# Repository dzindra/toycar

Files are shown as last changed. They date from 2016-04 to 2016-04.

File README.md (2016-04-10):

# WiFi controlled toy car

Made as a present for my friend's birthday 

* ESP-8266 with NodeMCU
* L293 dual H-bridge driver
* Small geared DC motors
* Pololu wheels and idler
* 3D printed case
* iOS app for car control

## Photos

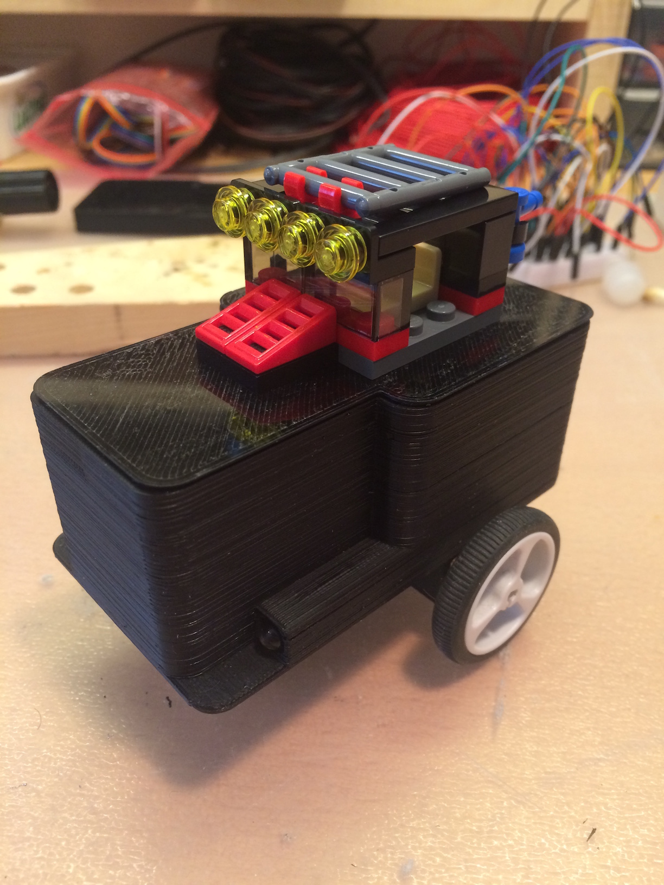
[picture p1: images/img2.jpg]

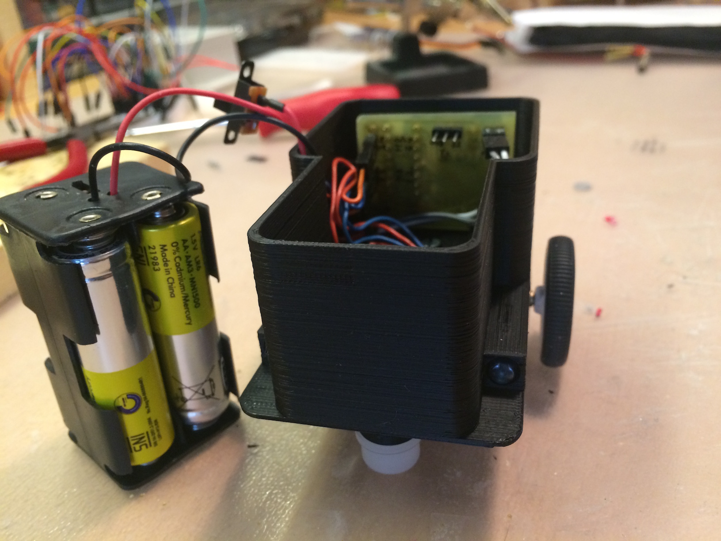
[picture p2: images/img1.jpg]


## Schematic and PCB

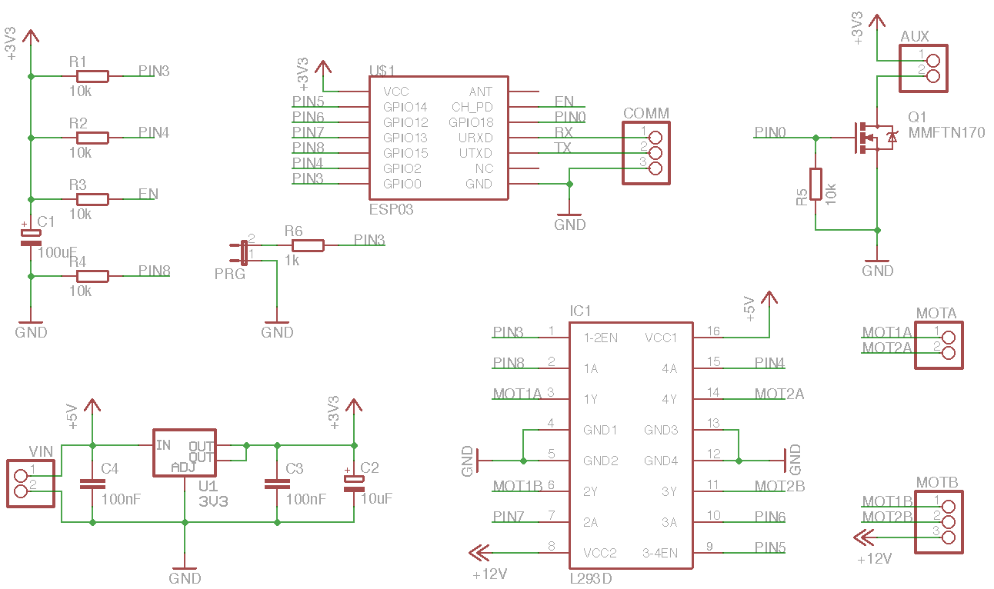
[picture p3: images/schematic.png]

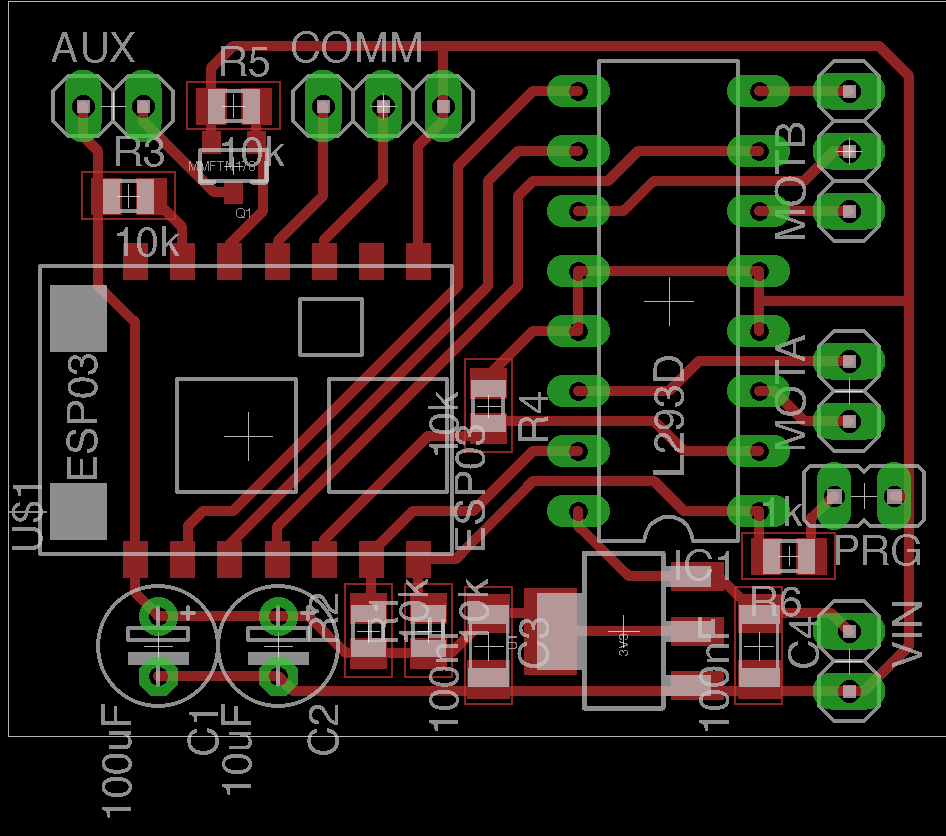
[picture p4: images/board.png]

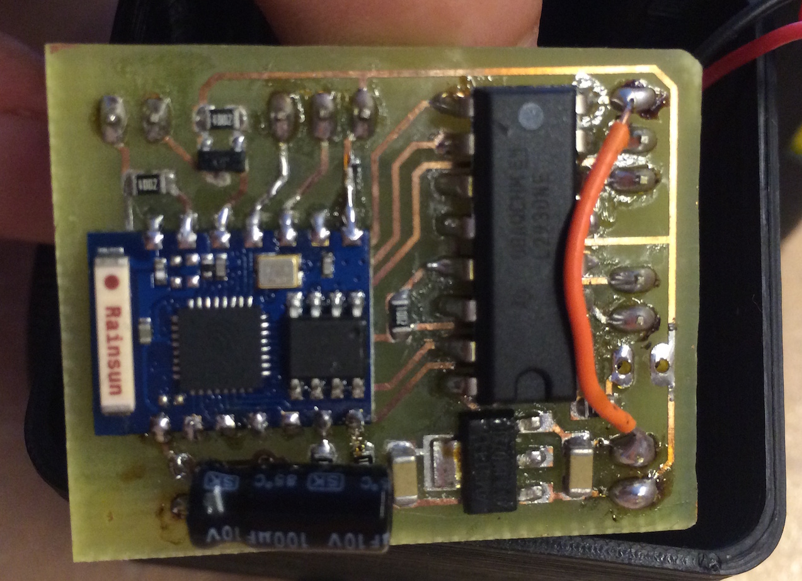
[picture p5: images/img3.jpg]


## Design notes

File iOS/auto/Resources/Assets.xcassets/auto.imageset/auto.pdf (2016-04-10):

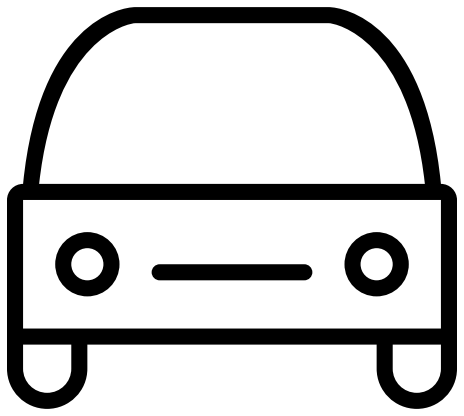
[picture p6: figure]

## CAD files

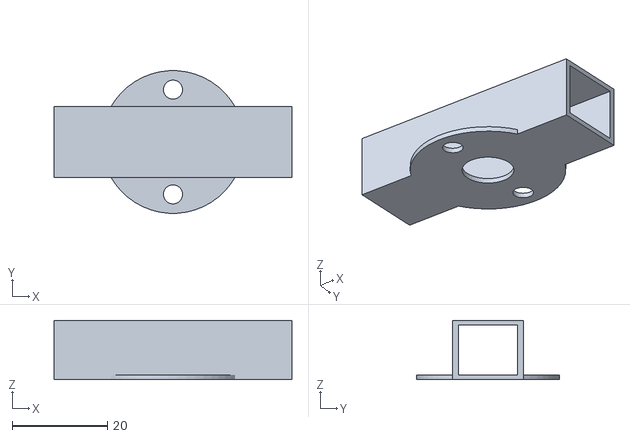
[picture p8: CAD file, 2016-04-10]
stl/motor-holder.stl
50.0 x 29.9 x 12.5

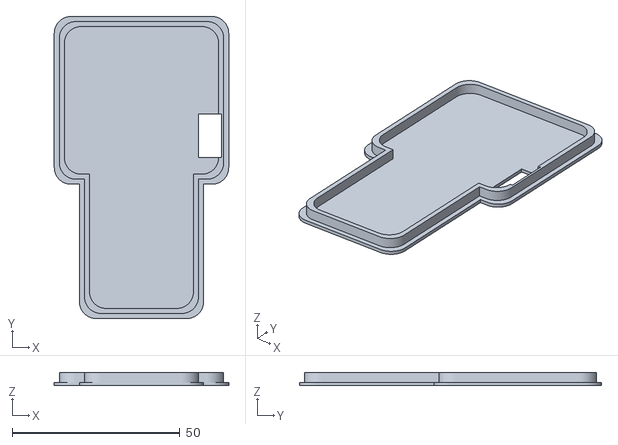
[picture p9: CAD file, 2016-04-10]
stl/top-lid.stl
52.0 x 90.0 x 4.00

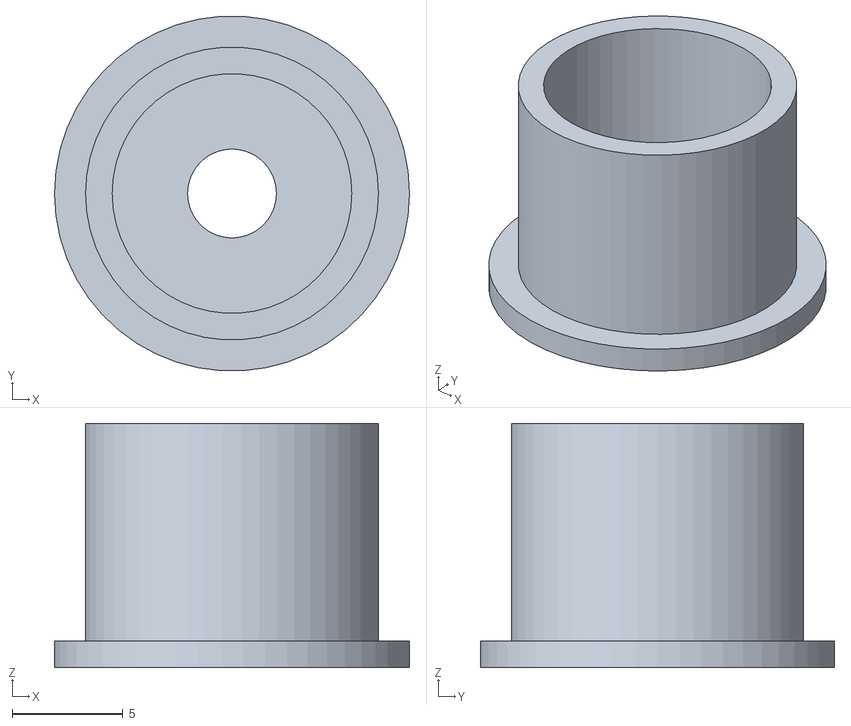
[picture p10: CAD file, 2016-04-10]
stl/idler.stl
16.0 x 16.0 x 11.0

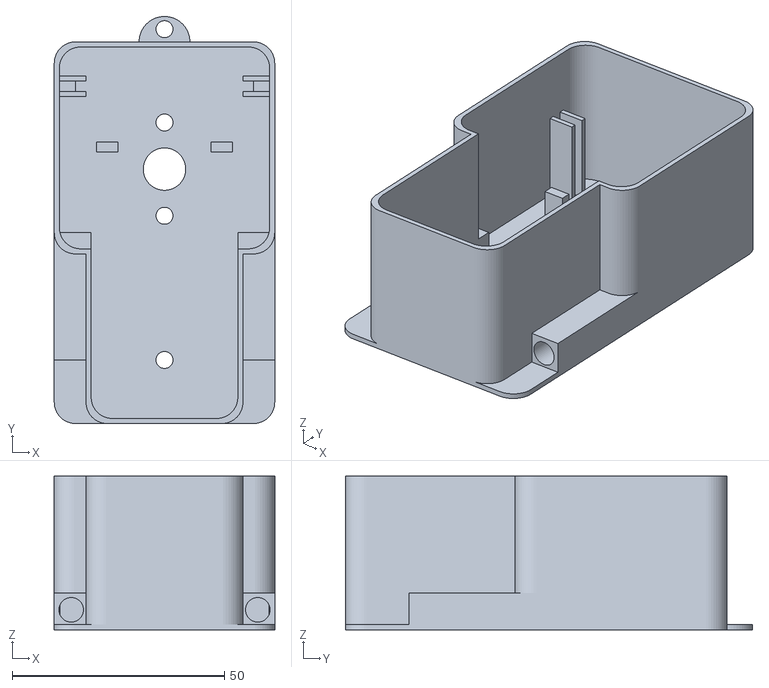
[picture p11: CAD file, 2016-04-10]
stl/body.stl
52.0 x 96.0 x 36.2

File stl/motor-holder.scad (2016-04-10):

wall = 1.2;
wallz = 1;

motorW = 12.5;
motorH = 10.5;

length = 50;

$fn = 50;

baseDia = 30;

difference() {
    union() {
        difference() {
            cube([length,motorW+wall*2,wallz*2+motorH]);
            translate([-1,wall,wallz]) cube([length+2, motorW, motorH]);
        }

        translate([length/2,(motorW+wall*2)/2,0]) difference() {
            cylinder(d=baseDia,h=wallz,$fn=$fn);
            translate([0,-11,-1]) cylinder(d=4,h=wallz+3,$fn=$fn);
            translate([0,11,-1]) cylinder(d=4,h=wallz+3,$fn=$fn);
        }
    }
    
    translate([length/2,(motorW+wall*2)/2,-1]) cylinder(d=10,h=wallz+2,$fn=$fn);
}

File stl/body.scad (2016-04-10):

wallZ = 1.2;
wall = 1.2;
width=52;
height=90;
corner=5;
$fn=50;

bottomHoleOffset=60;
bottomHoleOffset2=15;

frontBump=[37,40,35];


module roundRect(size,corner=5) {
    translate([corner,corner,0]) hull() {
        cube([size[0]-corner*2,size[1]-corner*2,size[2]]);
        cylinder(h=size[2],r=corner,$fn=$fn);
        translate([size[0]-corner*2,0,0]) cylinder(h=size[2],r=corner,$fn=$fn);
        translate([size[0]-corner*2,size[1]-corner*2,0]) cylinder(h=size[2],r=corner,$fn=$fn);
        translate([0,size[1]-corner*2,0]) cylinder(h=size[2],r=corner,$fn=$fn);
    }
}

module roundRectHollow(size,corner=5,wall=1) {
    difference() {
        roundRect(size);
        translate([wall,wall,-1]) roundRect([size[0]-wall*2,size[1]-wall*2,size[2]+2]);
    }
}

module pcbHolder(outerWidth=49.6, innerWidth=37, wall=1.2, pcbThickness=2.5, height=20) {
    w=(outerWidth-innerWidth)/2;
    cube([w,wall,height]);
    translate([0,wall+pcbThickness,0]) cube([w,wall,height]);
    translate([w+innerWidth,0,0]) cube([w,wall,height]);
    translate([w+innerWidth,wall+pcbThickness,0]) cube([w,wall,height]);
    
    translate([0,wall,0]) cube([w-2.5,pcbThickness,5]);
    translate([w+innerWidth+2.5,wall,0]) cube([w-2.5,pcbThickness,5]);
}

module ledHolder(size=[7.5,30,7.5],ledDia=5.8,ledBarrel=6,ledRim=7,right=1,hollow=1,wall=1.2) {
    d = (ledRim-ledDia)/2;
    difference() {
        cube([size[0]+wall,size[1],size[2]]);
        
        if (hollow) {
        if (right) {
            translate([-ledDia/2+size[0]-d,-1,ledDia/2+d]) rotate([-90,0,0]) cylinder(d=ledDia,h=ledBarrel+2,$fn=$fn);
            translate([-ledRim/2+size[0],ledBarrel,ledRim/2]) rotate([-90,0,0]) cylinder(d=ledRim,h=size[1]-ledBarrel+1,$fn=$fn);
        } else {
            translate([ledDia/2+d+wall,-1,ledDia/2+d]) rotate([-90,0,0]) cylinder(d=ledDia,h=ledBarrel+2,$fn=$fn);
            translate([ledRim/2+wall,ledBarrel,ledRim/2]) rotate([-90,0,0]) cylinder(d=ledRim,h=size[1]-ledBarrel+1,$fn=$fn);
        }
        }
    }

}

difference() {
    roundRect([width,height,wallZ]);

    translate([width/2, bottomHoleOffset, -1]) union() {
        cylinder(d=10,h=wallZ+2,$fn=$fn);
        translate([0,-11,0]) cylinder(d=4,h=wallZ+2,$fn=$fn);
        translate([0,11,0]) cylinder(d=4,h=wallZ+2,$fn=$fn);
    }
    translate([width/2, bottomHoleOffset2, -1]) cylinder(d=4,h=wallZ+2,$fn=$fn);
}


translate([width/2,height]) difference() {
    cylinder(d=12,h=wallZ,$fn=$fn);
    translate([0,3,-1]) cylinder(d=4,h=wallZ+2,$fn=$fn);
}

translate([0,0,wallZ]) {
    
     difference() {
        translate([(width-frontBump[0])/2,0,0]) roundRectHollow([frontBump[0],height,frontBump[2]], wall=wall);
        translate([0,frontBump[1],-1]) roundRect([width,height-frontBump[1],frontBump[2]+2]);
    }
    difference() {
        translate([0,frontBump[1],0])  roundRectHollow([width,height-frontBump[1],frontBump[2]],wall=wall);
        translate([(width-frontBump[0]+wall*2)/2,frontBump[1]-1,-1])
            cube([frontBump[0]-wall*2,wall+2,frontBump[2]+2]);
        
        translate([0,15,0]) ledHolder(hollow=0);
        translate([frontBump[0]+7.5-wall,15,0]) ledHolder(hollow=0,right=0);
    }
    translate([10,bottomHoleOffset+4,0]) cube([5,wall*2,10]);
    translate([width-15,bottomHoleOffset+4,0]) cube([5,wall*2,10]);
    
    translate([0,15,0]) ledHolder();
    translate([frontBump[0]+7.5-wall,15,0]) ledHolder(right=0);    
   
    translate([wall,height-8-2.5-wall*2,0]) pcbHolder(wall=wall);
}

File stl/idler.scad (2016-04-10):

wall = 1.2;
height = 10;
innerDia = 10.8;
outerDia = 16;
wallZ = 1;
$fn=50;

difference() {
    cylinder(d=outerDia,h=wall,$fn=$fn);
    translate([0,0,-1]) cylinder(d=4,h=wall+2,$fn=$fn);
}

translate([0,0,wallZ]) difference() {
    cylinder(d=innerDia+wall*2,h=height,$fn=$fn);
    translate([0,0,-1]) cylinder(d=innerDia,h=height+2,$fn=$fn);
}

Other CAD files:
stl/top-lid.scad

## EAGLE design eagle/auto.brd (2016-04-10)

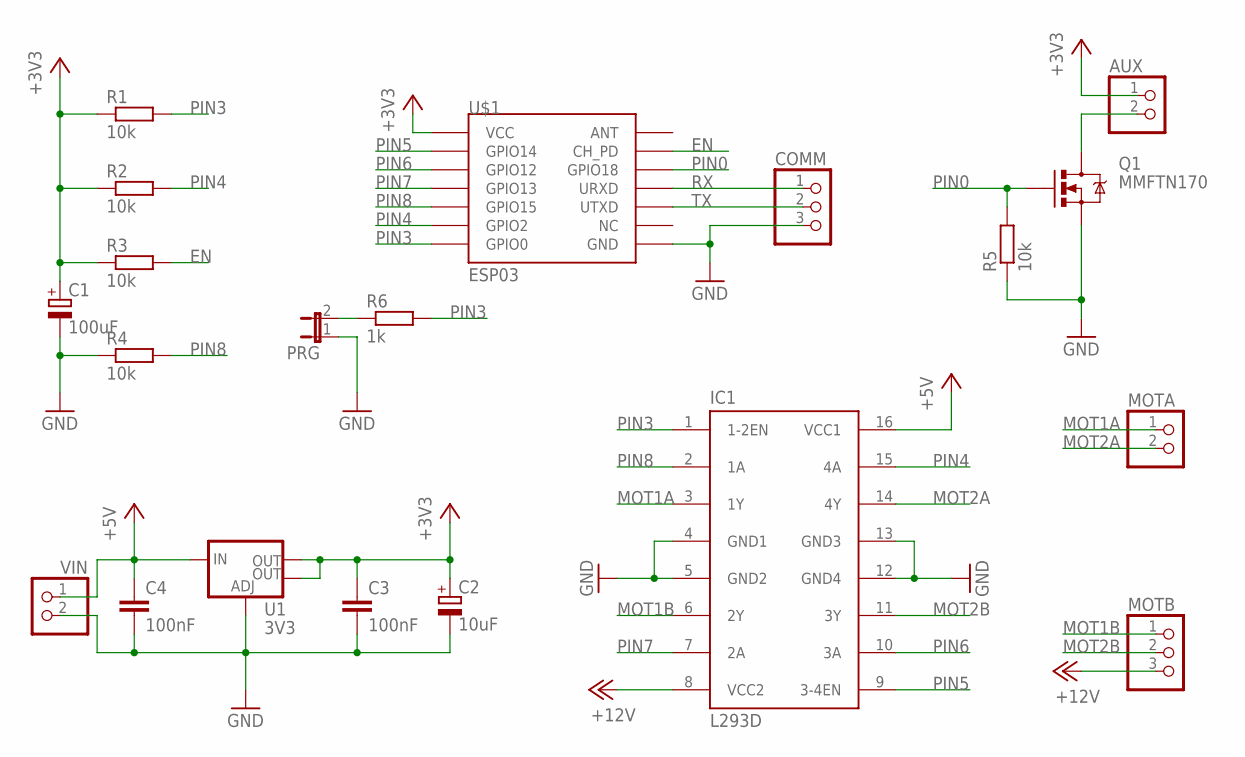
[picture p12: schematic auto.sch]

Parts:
AUX: PINHD-1X2; 1X02
C1: 100uF; E2,5-5
C2: 10uF; E2,5-5
C3, C4: 100nF; C1206
COMM: PINHD-1X3; 1X03
IC1: L293D; DIL16
MOTA: PINHD-1X2; 1X02
MOTB: PINHD-1X3; 1X03
PRG: JP1E; JP1
Q1: MMFTN170; SOT23-3
R1, R2, R3, R4, R5: 10k; R0805
R6: 1k; R0805
U1: 3V3; SOT223
U$1: ESP03
VIN: PINHD-1X2; 1X02

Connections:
+3V3: AUX.1, C1.+, C2.+, C3.1, R1.1, R2.1, R3.1, U1.2 (OUT), U1.4 (OUT), U$1.VCC
+5V: C4.1, IC1.16 (VCC1), U1.3 (IN), VIN.1
+12V: IC1.8 (VCC2), MOTB.3
EN: R3.2, U$1.CH_PD
GND: C1.-, C2.-, C3.2, C4.2, COMM.3, IC1.4 (GND1), IC1.5 (GND2), IC1.12 (GND4), IC1.13 (GND3), PRG.1, Q1.2 (S), R4.1, R5.1, U1.1 (ADJ), U$1.GND, VIN.2
MOT1A: IC1.3 (1Y), MOTA.1
MOT1B: IC1.6 (2Y), MOTB.1
MOT2A: IC1.14 (4Y), MOTA.2
MOT2B: IC1.11 (3Y), MOTB.2
unnamed: AUX.2, Q1.3 (D)
unnamed: PRG.2, R6.1
PIN0: Q1.1 (G), R5.2, U$1.GPIO18
PIN3: IC1.1 (1-2EN), R1.2, R6.2, U$1.GPIO0
PIN4: IC1.15 (4A), R2.2, U$1.GPIO2
PIN5: IC1.9 (3-4EN), U$1.GPIO14
PIN6: IC1.10 (3A), U$1.GPIO12
PIN7: IC1.7 (2A), U$1.GPIO13
PIN8: IC1.2 (1A), R4.2, U$1.GPIO15
RX: COMM.1, U$1.URXD
TX: COMM.2, U$1.UTXD

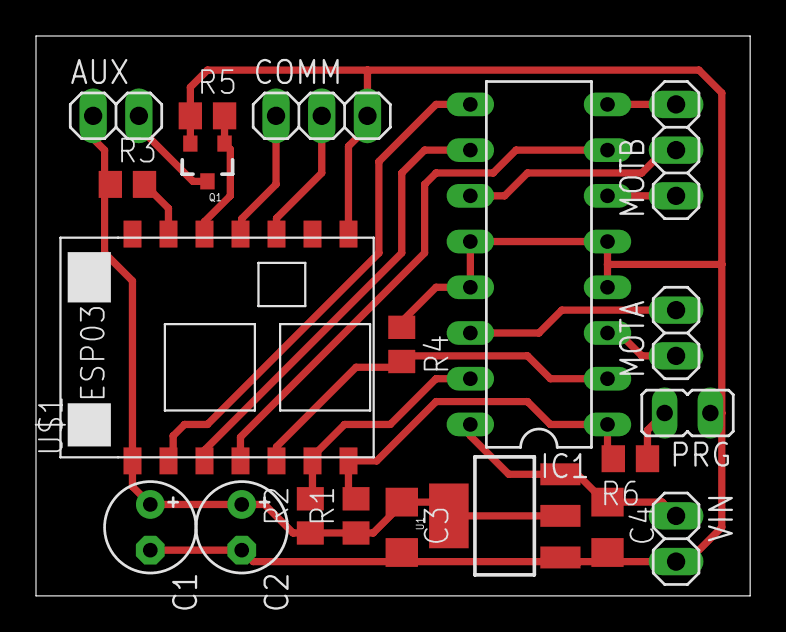
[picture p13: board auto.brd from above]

Board: 2 copper layers, 39.7 x 31.1 mm, 20 parts (0 on the bottom side), 20 nets.

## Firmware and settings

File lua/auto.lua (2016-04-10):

local M = {
    pinConfig = {
        m1a=8,
        m1b=7,
        m1e=3,
        m2a=4,
        m2b=6,
        m2e=5,
        aux=0
    },
    port=6666,
    blinkC=0
}

function M.drive(m1, m2)
    if m1>0 then
        gpio.write(M.pinConfig.m1a,gpio.HIGH)
        gpio.write(M.pinConfig.m1b,gpio.LOW)
        pwm.setduty(M.pinConfig.m1e, m1)
    elseif m1<0 then
        gpio.write(M.pinConfig.m1a,gpio.LOW)
        gpio.write(M.pinConfig.m1b,gpio.HIGH)
        pwm.setduty(M.pinConfig.m1e, -m1)
    else
        gpio.write(M.pinConfig.m1a,gpio.HIGH)
        gpio.write(M.pinConfig.m1b,gpio.HIGH)
        pwm.setduty(M.pinConfig.m1e, 0)
    end

    if m2>0 then
        gpio.write(M.pinConfig.m2a,gpio.HIGH)
        gpio.write(M.pinConfig.m2b,gpio.LOW)
        pwm.setduty(M.pinConfig.m2e, m2)
    elseif m2<0 then
        gpio.write(M.pinConfig.m2a,gpio.LOW)
        gpio.write(M.pinConfig.m2b,gpio.HIGH)
        pwm.setduty(M.pinConfig.m2e, -m2)
    else
        gpio.write(M.pinConfig.m2a,gpio.HIGH)
        gpio.write(M.pinConfig.m2b,gpio.HIGH)
        pwm.setduty(M.pinConfig.m2e, 0)
    end
end

function M.aux(on)
    if on then
        gpio.write(M.pinConfig.aux, gpio.HIGH)
    else
        gpio.write(M.pinConfig.aux, gpio.LOW)
    end
end

function M.stop()
    if M.server then
        M.server:close()
        M.server = nil
    end
end

function M.blink(count, delay)
    M.blinkC = count
    if count>0 then
        M.aux(true)
        tmr.alarm(2,delay,tmr.ALARM_SINGLE, function()
            M.aux(false)
            tmr.alarm(3,delay,tmr.ALARM_SINGLE, function ()
                M.blink(count-1, delay)
            end)
        end)
    end
end

function M.start()
    M.stop()
    
    for k,v in pairs(M.pinConfig) do
        gpio.mode(v, gpio.OUTPUT)
        gpio.write(v, gpio.LOW)
    end

    pwm.setup(M.pinConfig.m1e, 100, 0)
    pwm.setup(M.pinConfig.m2e, 100, 0)

    M.server = net.createServer(net.UDP)
    M.server:on("receive", function(srv, pl)
        local m1,m2,aux = pl:match("^A([0-9A-F][0-9A-F][0-9A-F])([0-9A-F][0-9A-F][0-9A-F])(%d)$")
        if m1 == nil then
            return
        end

        m1 = tonumber(m1, 16)
        m2 = tonumber(m2, 16)
        aux = tonumber(aux)

        if m1>2046 then m1=1023 else m1=m1-1023 end
        if m2>2046 then m2=1023 else m2=m2-1023 end

        M.drive(m1,m2)
        if M.blinkC == 0 then
            M.aux(aux ~= 0)
        end
    end)
    M.server:listen(M.port)
end

return M

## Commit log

2016-04-10 Add schematic and board layout
    [auto.brd, auto.sch]
2016-04-10 Add 3D models
    [body.scad, body.stl, idler.scad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]

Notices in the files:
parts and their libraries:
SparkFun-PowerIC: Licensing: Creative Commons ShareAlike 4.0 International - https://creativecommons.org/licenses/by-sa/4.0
